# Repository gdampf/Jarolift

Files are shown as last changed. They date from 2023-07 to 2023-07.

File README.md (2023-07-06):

# Jarolift/Jarolador
Jarolift is offering shutter motors with embedded 433MHz remote receiver. The remote controller TDRC 04 has 4 LEDs to signal the current channel to control up to 4 independent shutter.
It has 4 Buttons, one to select the channel, one to open the shutter (up), one to close the shutter (down) and one to stop the current movements (stop).
A direct control of the 433MHz Signal is difficult because of the rolling code they use. I tried several solutions, but they are not that reliable as the original remote is.
As far as such a remote is costing just a few Euro and can be purchased used for even less, it isn't worth to try to make the remote by yourself. Just use a real remote and control it by an ESP8266.

The idea is to use an ESP-07S for controlling a standard Jarolift Remote control via MQTT.

In use are Channel 0-4: 0 means all channels 1-4 are affected in parallel, channel 1-4 means shutter 1-4 as on your remote.

You can build this on a bread board (see fritzing) or use my PCB (Jarollator).

If somebody has build a nice housing on 3d-printer for the cirquit and the remote, let me know.

To be used with VSCode Version: 1.79.2 (user setup)
and Platformio 6.1.7, but the versions shouldn't mean that much.
For Versions on Libraries, see the platformio.ini.template!

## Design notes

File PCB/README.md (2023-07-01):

# EasyEDA PCB
The idea is to use an ESP-07S for controlling a standard Jarolift Remote control via MQTT.
The PCB contains 2 Transistors (Q1 & Q2) for easy programming via PL2 as serial interface.
Further there are 4 Transistors connected to the LEDs of the Jarolift Remote Control to detect the current active channel and signal its state to IO13, IO16, IO02 and IO00 in that order for Channel 1-4.
TR1 is providing the necessary Voltage of 3,3V. I connected VCC to the Battery-connector (+) of the Remote control via a standard shotkey diode to reduce it to 3 V for the remote. Also Gnd is connected.
The 4 Keys (Up, Down, Stop and Select) are connected to the corresponding pins (IO05, IO14, IO04 and IO12), which pull them to ground as a keypress would do.
See Schematics for further details.

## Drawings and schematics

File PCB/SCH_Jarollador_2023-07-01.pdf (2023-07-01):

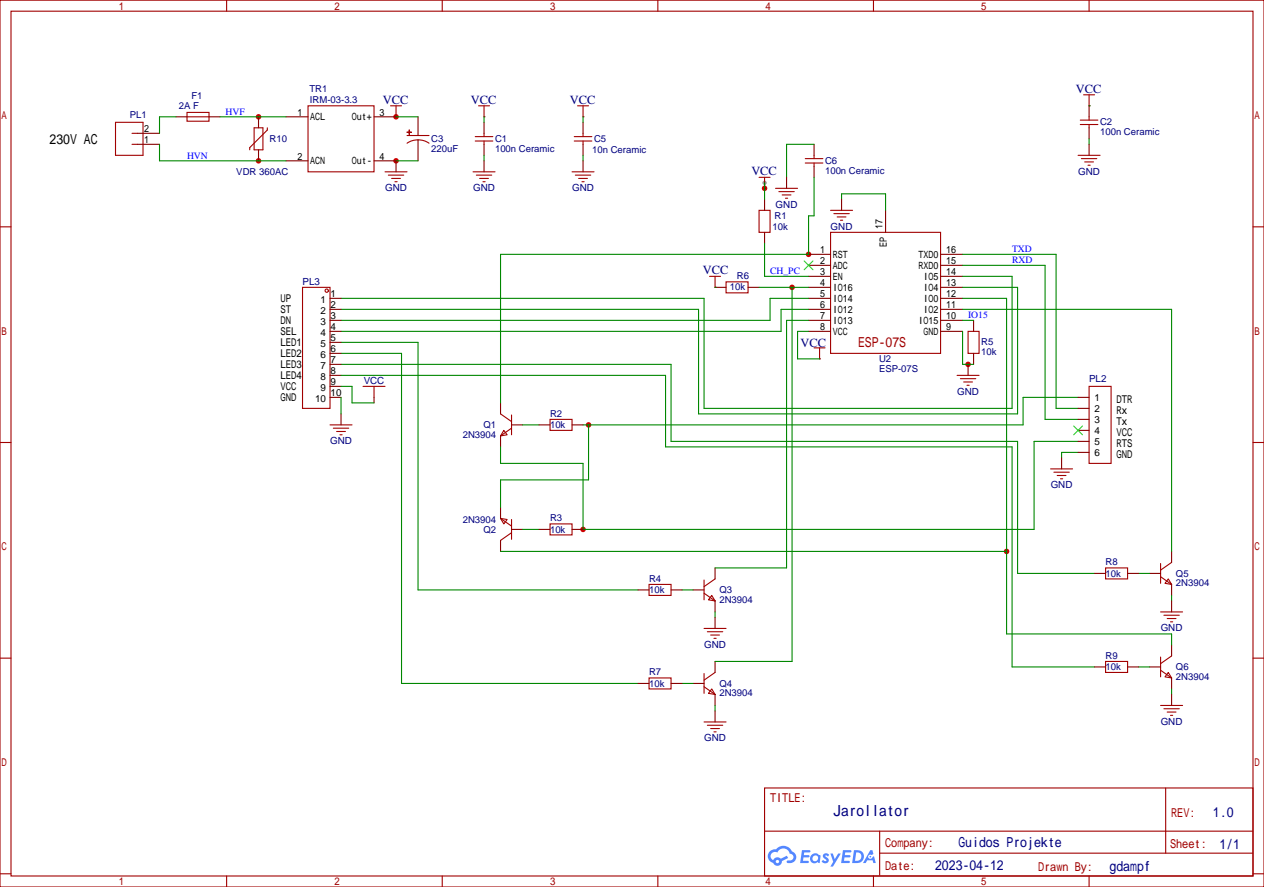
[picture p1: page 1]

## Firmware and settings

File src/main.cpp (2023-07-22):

#include "Version.h"
#include <Arduino.h>
#include <settings.h>
#include <string.h>
#include <ESP8266WiFi.h>
#include <ESP8266mDNS.h>
#include <WiFiUdp.h>
#include <ArduinoOTA.h>
#include <WiFiClientSecure.h>
#include <PubSubClient.h>
#include <NTPtimeESP.h>

#if !defined(ESP8266)
  #error This code is designed to run on ESP8266 only
#endif

#ifdef USECERT
  X509List cert(CA_CERT);
#endif

const char* ssid = STASSID;
const char* password = STAPSK;

#ifdef USETLS
  WiFiClientSecure espClient;
#else
  WiFiClient espClient;
#endif
PubSubClient client(espClient);

void delay_OTA(unsigned long msec = 0)
{
  if (msec == 0)
  {
    client.loop();
    ArduinoOTA.handle();
    yield();    
    return;
  }

  unsigned long stopm = millis();
  while (stopm > millis() - msec)
  {
    client.loop();
    ArduinoOTA.handle();
    yield();    
  }
}

enum State { lazy, selectr, waitforled, selnohit, selhit, cmdsend, endwait };
enum Cmd { none = 0, up = 1, stop = 2, down = 3 };
Cmd cmdqueue[5] = { none };
int cur_RolNo = -1;
unsigned long last_event = millis();
Cmd cur_Cmd = none;

char Datum[30];

void update_time() {
  static NTPtime NTPch(ntp_server);
  static strDateTime dateTime;

  int i = 0;
  do
  {
    dateTime = NTPch.getNTPtime(1.0,1);
    if (!dateTime.valid) delay(100);  
    #ifdef DEBUG
      Serial.print(".");
    #endif
  } while (!dateTime.valid and i++ < 50);  

  if(!dateTime.valid){
    #ifdef DEBUG
      Serial.println(F("Failed to obtain time"));
    #endif
    return;
  }
  sprintf(Datum,"%02d.%02d.%04d %02d:%02d",dateTime.day, dateTime.month, dateTime.year, dateTime.hour, dateTime.minute);

  #ifdef DEBUG
    Serial.printf("NTP: %d %s:%02d\n", dateTime.dayofWeek-1, Datum, dateTime.second);
  #endif
}

void tspublish(const char *topic, const char *payload) {
  String pl;
  static unsigned long seq = 0;
  pl = Datum + String("-") + (seq++) + String(":") + payload;
  client.publish(topic,pl.c_str(),true);
}

void callback(char* topic, byte* payload, unsigned int length) {
  char spayload[3];
  int RolNo;

  if (length == 0) return;
  int b = strlen(mqtt_stopic);
  if (strncmp(topic,mqtt_stopic,b) == 0) return;
  b = strlen(mqtt_etopic);
  if (strncmp(topic,mqtt_etopic,b) == 0) return;
  b = strlen(mqtt_topic)-2;
  if (strncmp(topic,mqtt_topic,b)) {
    #ifdef DEBUG
      Serial.println("Ungültiges Topic!");
    #endif
    tspublish(mqtt_etopic,"Ungültiges Topic!");
    return;
  }
  int o = strlen(topic)-b;
  if (o == 0) RolNo = 0;
  else if (o == 2 && topic[b+o-2] == '/') {
    RolNo = topic[b+o-1] - '0';
    if (RolNo < 0 || RolNo > 4) RolNo = -1;
  }
  else RolNo = -1;

  if (RolNo < 0) {
    #ifdef DEBUG
      Serial.println("Ungültiger Rollladen!");
    #endif
    tspublish(mqtt_etopic,"Ungültiger Rollladen!");
    return;
  }
  if (length == 0) return;
  if (length != 2) {
    #ifdef DEBUG
      Serial.println("Ungültige Befehlslänge!");
    #endif
    tspublish(mqtt_etopic,"Ungültige Befehlslänge!");
    return;
  }

  int j = 0;
  for (unsigned int i = 0; i < length; i++) {
    if (payload[i] > 32) spayload[j++] = toUpperCase(payload[i]);
  }
  spayload[j] = '\0';
  #ifdef DEBUG
    Serial.printf("Nachricht für %d empfangen: %s\n",RolNo,spayload);
  #endif
  if (strcmp(spayload,"UP") == 0) cmdqueue[RolNo] = up;
  else if (strcmp(spayload,"DN") == 0) cmdqueue[RolNo] = down;
  else if (strcmp(spayload,"ST") == 0) cmdqueue[RolNo] = stop;
  else {
    #ifdef DEBUG
      Serial.println("Kenne Befehl nicht!");
    #endif
    tspublish(mqtt_etopic,"Kenne Befehl nicht!");
    return;
  }
  #ifdef DEBUG
    Serial.printf("Befehl erkannt: %d\n",cmdqueue[RolNo]);
  #endif
}

void reconnect() {
  while (!client.connected()) {
    if (client.connect(HOSTNAME, mqtt_user, mqtt_pass)) {
      #ifdef DEBUG
        Serial.println("connected.");
      #endif
  
      if (client.subscribe(mqtt_topic)) {
        #ifdef DEBUG
          Serial.print(F("subscribed to "));
          Serial.println(mqtt_topic);
        #endif
      }
      else {
        #ifdef DEBUG
          Serial.println("subscribe failed!");
        #endif
      }
    }
    else {
      #ifdef DEBUG
        Serial.print(F("failed, status code = "));
        Serial.println(client.state());
        #ifdef USETLS
          char errt[50];
          Serial.print(F("LastSSLError = "));
          espClient.getLastSSLError(errt, 50);
          Serial.println(errt);
        #endif
      #endif
      delay_OTA(2000);
    }
  }
  update_time();
  tspublish(mqtt_stopic,"New Connected by " VersionString);
}

void setup() {
  #ifdef DEBUG
    Serial.begin(115200);
    Serial.println(F("Booting"));
    Serial.printf("Project version v%s, built %s\n",VERSION,BUILD_TIMESTAMP);
  #endif

  pinMode(PIN_OUT1, OUTPUT_OPEN_DRAIN);
  digitalWrite(PIN_OUT1, HIGH);
  pinMode(PIN_OUT2, OUTPUT_OPEN_DRAIN);
  digitalWrite(PIN_OUT2, HIGH);
  pinMode(PIN_OUT3, OUTPUT_OPEN_DRAIN);
  digitalWrite(PIN_OUT3, HIGH);
  pinMode(PIN_OUT4, OUTPUT_OPEN_DRAIN);
  digitalWrite(PIN_OUT4, HIGH);

  // All input need Pullup
  pinMode(PIN_IN1, PINMODE1);
  pinMode(PIN_IN2, PINMODE2);
  pinMode(PIN_IN3, PINMODE3); 
  pinMode(PIN_IN4, PINMODE4); 

  WiFi.mode(WIFI_STA);
  WiFi.begin(ssid, password);
  while (WiFi.waitForConnectResult() != WL_CONNECTED) {
    #ifdef DEBUG
      Serial.println(F("Connection Failed! Rebooting..."));
    #endif
    delay(5000);
    ESP.restart();
  }

  #ifdef USETLS
    #ifdef USECERT
      espClient.setTrustAnchors(&cert);
    #else
      #ifdef USEFP
        espClient.setFingerprint(fingerprint);
      #else
        espClient.setInsecure();
      #endif
    #endif
  #endif
  client.setServer(mqtt_server, mqtt_port);
  client.setCallback(callback);
  client.setKeepAlive(UPTIMESEC>DNTIMESEC?UPTIMESEC:DNTIMESEC);

  // Port defaults to 8266
  ArduinoOTA.setPort(8266);

  // Hostname defaults to esp8266-[ChipID]
  ArduinoOTA.setHostname(HOSTNAME);

  // No authentication by default
  ArduinoOTA.setPassword(OTA_PWD);

  // Password can be set with it's md5 value as well
  // MD5(admin) = 21232f297a57a5a743894a0e4a801fc3
  // ArduinoOTA.setPasswordHash("21232f297a57a5a743894a0e4a801fc3");

  ArduinoOTA.onStart([]() {
    if (ArduinoOTA.getCommand() == U_FLASH) {
      #ifdef DEBUG
        Serial.println(F("Start updating sketch"));
      #endif
    } else { // U_FS
      #ifdef DEBUG
        Serial.println(F("Start updating filesystem"));
      #endif
    }

    // NOTE: if updating FS this would be the place to unmount FS using FS.end()
  });
  ArduinoOTA.onEnd([]() {
    #ifdef DEBUG
      Serial.println(F("\nEnd"));
    #endif
  });
  ArduinoOTA.onProgress([](unsigned int progress, unsigned int total) {
    #ifdef DEBUG
      Serial.printf("Progress: %u%%\r", (progress / (total / 100)));
    #endif
  });
  ArduinoOTA.onError([](ota_error_t error) {
    #ifdef DEBUG
      Serial.printf("Error[%u]: ", error);
      if (error == OTA_AUTH_ERROR) {
        Serial.println(F("Auth Failed"));
      } else if (error == OTA_BEGIN_ERROR) {
        Serial.println(F("Begin Failed"));
      } else if (error == OTA_CONNECT_ERROR) {
        Serial.println(F("Connect Failed"));
      } else if (error == OTA_RECEIVE_ERROR) {
        Serial.println(F("Receive Failed"));
      } else if (error == OTA_END_ERROR) {
        Serial.println(F("End Failed"));
    }
    #endif
  });
  ArduinoOTA.begin();

  #ifdef DEBUG
    Serial.println(F("Ready"));
    Serial.print(F("IP address: "));
    Serial.println(WiFi.localIP());
  #endif
}

void loop() {
  if (!client.loop()) {
    reconnect();
  } 
  else {
    #ifdef DEBUG
      static unsigned long pause = millis();
      if (millis() - pause > 10000) {
        Serial.println(F("still connected..."));
        pause = millis();
      }
    #endif
  }

  #ifndef dryrun
    static State s = lazy;
    static String ss;

    static bool changed = false;
    #ifdef DEBUG
      static bool changed2 = false;
    #endif
    static const unsigned int pinin[4] = { PIN_IN1, PIN_IN2, PIN_IN3, PIN_IN4 };
    static const uint32_t mask = (1 << PIN_IN1) | (1 << PIN_IN2) | (1 << PIN_IN3) | (1 << PIN_IN4);
    static uint32_t old_in_all = mask;
    static unsigned long last_select = millis() - 11;
    static uint32_t in_all = old_in_all;
    if (millis() - last_select > 10) in_all = ((GPI & 0xffff) | ((GP16I & 1) << 16)) & mask; 
    if (old_in_all != in_all ) {
      old_in_all = in_all; 
      changed = true; 
      #ifdef DEBUG
        changed2 = true;
      #endif
    }
    delay_OTA();

    #ifdef DEBUG
      if (changed2) {
        Serial.print(F("LED-Status: "));
        Serial.println(in_all,BIN);
        changed2 = false;
      }
    #endif
  
    //RolNo: 0 = ALL, 1-4 = Rollo 1-4
    switch(s) {
      case lazy:
        for (int i = 0; i < 5; i++) {
          if (cmdqueue[i] != none) {
            // activate select
            digitalWrite(PIN_OUT4, LOW);
            // next_event = now + 100 ms
            last_event = millis();
            last_select = last_event;
            #ifdef DEBUG
              Serial.printf("Signal 4 low at %lu\n",last_event);
            #endif
            cur_Cmd = cmdqueue[i];
            cur_RolNo = i;
            cmdqueue[i] = none;
            s = selectr;
            break;
          } 
        }
        if (s == lazy && UPDATEPERIOD < millis() - last_event) {
          last_event = millis();
          if (ss.length() > 0) {
            ss = String(VersionString) + String(" - Last Cmds done") + ss;
            tspublish(mqtt_stopic,ss.c_str());
            ss = "";
          }
          update_time();
        }  
        break;
      case selectr:
        if (millis() - last_event > PRESSDURATIONSEL) {
          // deactivate select
          digitalWrite(PIN_OUT4, HIGH);
          last_event = millis();
          #ifdef DEBUG
            Serial.printf("Signal 4 high at %lu\n",last_event);
          #endif
		      s = waitforled;
	      }
		    break;
	    case waitforled:
        if (changed) {
          changed = false;
          int curSel = 0;
          int cnt = 0;
          for (int i=0; i<4; i++) if (((in_all >> pinin[i]) & 1) == 0) {curSel = i+1; cnt++;}
          if ((cnt == 4 && cur_RolNo == 0) || (cnt == 1 && curSel == cur_RolNo)) s = selhit;
          else s = selnohit;
        } else if (millis() - last_event > WAITLEDDURATION) s = selnohit;
        break;
      case selnohit:
        if (millis() - last_event > RELEASEDURATION) {
          // activate select
          digitalWrite(PIN_OUT4, LOW);
          // next_event = now + 100 ms
          last_event = millis();
          #ifdef DEBUG
            Serial.printf("Signal 4 low at %lu\n",last_event);
          #endif
          s = selectr;
        }
        break;
      case selhit:
        if (millis() - last_event > RELEASEDURATION) {
          last_event = millis();
          switch(cur_Cmd) {
            case up:
              digitalWrite(PIN_OUT1, LOW);           
              #ifdef DEBUG
                Serial.printf("Signal 1 low at %lu\n",last_event);
              #endif
              s = cmdsend;
              break;
            case stop:
              digitalWrite(PIN_OUT2, LOW);           
              #ifdef DEBUG
                Serial.printf("Signal 2 low at %lu\n",last_event);
              #endif
              s = cmdsend;
              break;
            case down:
              digitalWrite(PIN_OUT3, LOW);           
              #ifdef DEBUG
                Serial.printf("Signal 3 low at %lu\n",last_event);
              #endif
              s = cmdsend;
              break;
            default:
              s = lazy;
          }
        }
        break;
      case cmdsend:
        if (millis() - last_event > PRESSDURATIONACT) {
          last_event = millis();
          // deactivate CMD
          switch(cur_Cmd) {
            case up:
              digitalWrite(PIN_OUT1, HIGH);           
              #ifdef DEBUG
                Serial.printf("Signal 1 high at %lu\n",last_event);
              #endif
              s = endwait;
              break;
            case stop:
              digitalWrite(PIN_OUT2, HIGH);           
              #ifdef DEBUG
                Serial.printf("Signal 2 high at %lu\n",last_event);
              #endif
              s = endwait;
              break;
            case down:
              digitalWrite(PIN_OUT3, HIGH);          
              #ifdef DEBUG
                Serial.printf("Signal 3 high at %lu\n",last_event);
              #endif
              s = endwait;
              break;
            default:
              s = lazy;
          }
          ss += String(" : ") + String(cur_RolNo) + String("/") + String(cur_Cmd == up ? "UP" : cur_Cmd == stop ? "ST" :  cur_Cmd == down ? "DN" : "__");
          cur_Cmd = none;
        }
        break;
      case endwait:
        if (millis() - last_event > RELEASEDURATION) s = lazy;
    }
  #endif

  delay_OTA(1);
}

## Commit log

2023-07-01 Create PCB Folder
2023-07-01 Initial load of PCB Files
2023-07-01 Add Fritzing
    [Jarolator.fzz]
2023-07-06 Status and Error Publishing
    [main.cpp]
2023-07-06 Fix NTP Request Period
    [main.cpp]
2023-07-07 Fixed error in Time-Update-Timing
    [main.cpp]
2023-07-15 Switch from digitalRead to GPI / GP16I Register
2023-07-22 add fingerprinting to SSL usage
